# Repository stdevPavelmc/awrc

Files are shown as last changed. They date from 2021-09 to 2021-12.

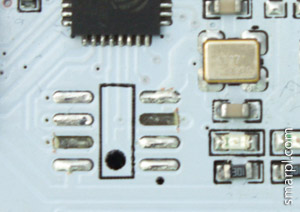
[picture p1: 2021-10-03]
doc/freeing up GPIO9 and GPIO10 smarpl.com_files/ESP8266-ESP-201-GPIO-mod-step3-IMG_7929.jpg

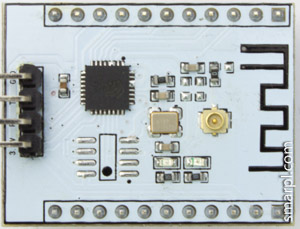
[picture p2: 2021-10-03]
doc/freeing up GPIO9 and GPIO10 smarpl.com_files/ESP8266-ESP-201-GPIO-mod-step1-IMG_7922.jpg

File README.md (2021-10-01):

# Amateur Wireless Rotor Controller

An arduino based rotor controller connected via WiFi using the ESP8266 MCU

## Rationale

Why use cables when you have wifi around?

The hamlib project has a simple TCP daemon for abstract the rotor control, so we implemented the basic commands for that protocol and simulate a `rotctld` instance right on the rotor hardware; as today most of the softwares I use supports rotctld directly.

A web interface with position and simple commands is built on, I will improve it with time but this is low priority.

## How to compile

We use platformio, not the Arduino IDE, and main development is on linux (It must work on Windows/Mac), so you need Vscode/Codium and the Platformio addon.

By now I'm managing the dependencies as git submodules, so to install them you must do on the console this:

```sh
git clone https://github.com/stdevPavelmc/awrc.git
cd awrc
git submodule update
```

I will port them to platformio.ini deps in the future. Now just open the Platformio IDE and open the project and run. If you have internet plarformio will install the frameworks and tools for you.

## Hardware

There is a folder named `awrc-kicad` that has the project for board and schematics.

## This is a work in progress

Until labeled otherwise this project is an `alpha` code.

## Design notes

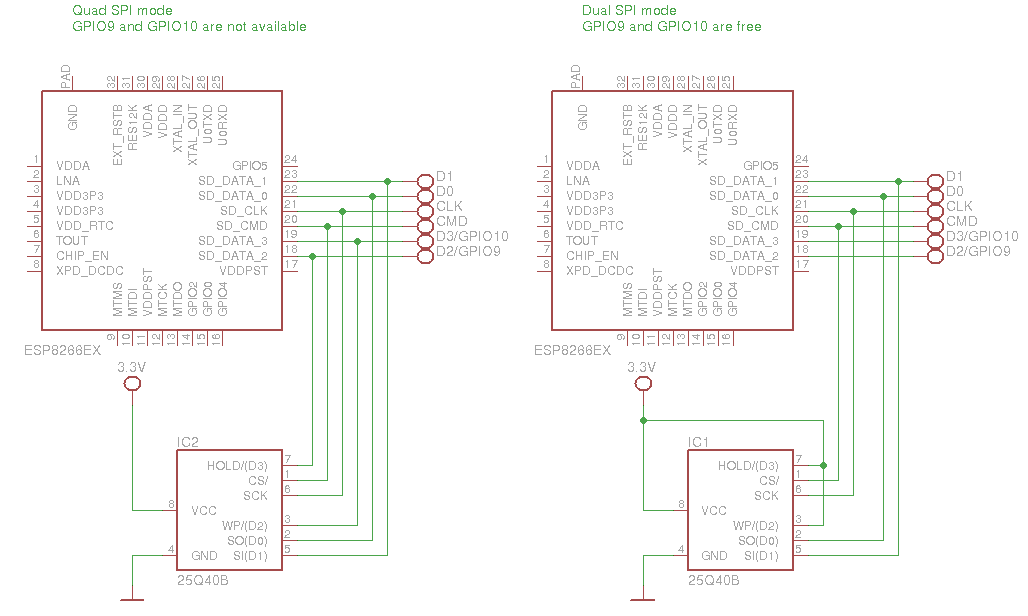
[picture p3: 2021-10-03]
doc/freeing up GPIO9 and GPIO10 smarpl.com_files/ESP8266-ESP-201-GPIO9-GPIO10-schematics.png

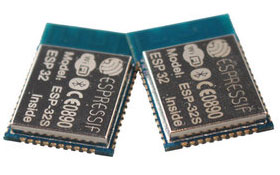
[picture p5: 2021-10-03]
doc/freeing up GPIO9 and GPIO10 smarpl.com_files/esp32s-x2-280.jpg

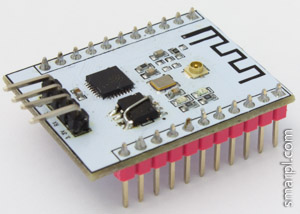
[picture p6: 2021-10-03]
doc/freeing up GPIO9 and GPIO10 smarpl.com_files/ESP8266-ESP-201-GPIO9-GPIO10-mod-IMG_7953.jpg

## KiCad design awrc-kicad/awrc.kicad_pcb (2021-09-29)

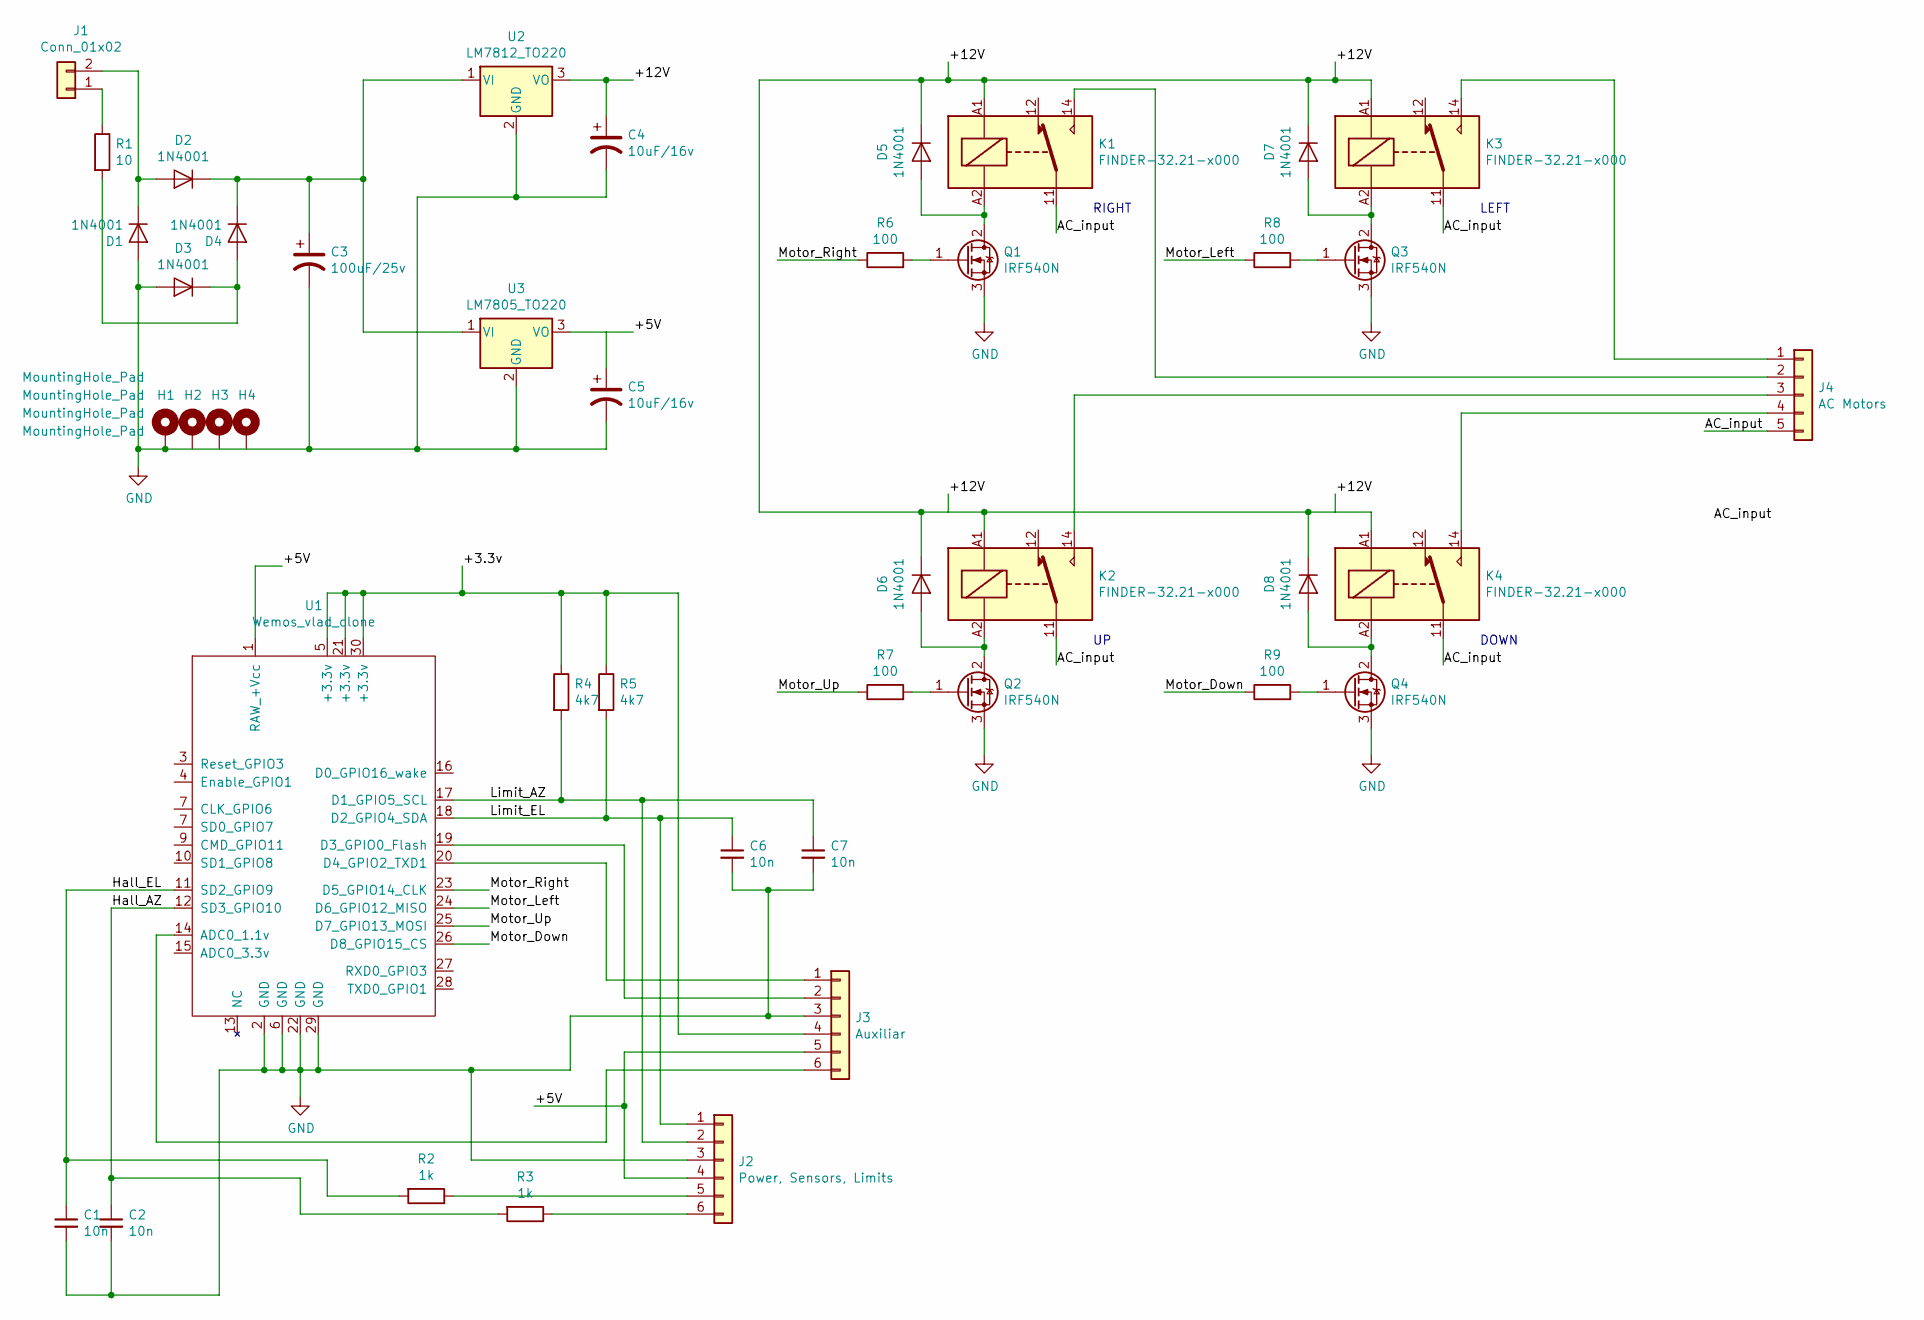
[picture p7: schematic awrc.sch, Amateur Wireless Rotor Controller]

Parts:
C1, C2, C6, C7: 10n; C_Disc_D7.5mm_W2.5mm_P5.00mm
C3: 100uF/25v; CP_Radial_D13.0mm_P5.00mm
C4, C5: 10uF/16v; CP_Radial_D10.0mm_P5.00mm
D1, D2, D3, D4, D5, D6, D7, D8: 1N4001; D_DO-41_SOD81_P10.16mm_Horizontal
H1, H2, H3, H4: MountingHole_Pad; MountingHole_3.2mm_M3_DIN965_Pad
J1: Conn_01x02; PinHeader_1x02_P2.54mm_Vertical
J2: Power, Sensors, Limits; PinHeader_1x06_P2.54mm_Vertical
J3: Auxiliar; PinHeader_1x06_P2.54mm_Vertical
J4: AC Motors; TerminalBlock_bornier-5_P5.08mm
K1, K2, K3, K4: FINDER-32.21-x000; Relay_THT_UPS_80H-1C-S
Q1, Q2, Q3, Q4: IRF540N; TO-220-3_Vertical
R1: 10; R_Axial_DIN0207_L6.3mm_D2.5mm_P10.16mm_Horizontal
R2, R3: 1k; R_Axial_DIN0207_L6.3mm_D2.5mm_P10.16mm_Horizontal
R4, R5: 4k7; R_Axial_DIN0207_L6.3mm_D2.5mm_P10.16mm_Horizontal
R6, R7, R8, R9: 100; R_Axial_DIN0207_L6.3mm_D2.5mm_P10.16mm_Horizontal
U1: Wemos_vlad_clone; Wemos_Clone
U2: LM7812_TO220; TO-220-3_Vertical
U3: LM7805_TO220; TO-220-3_Vertical

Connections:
/+3.3v: J3.4, R4.1, R5.1, U1.5 (+3.3v), U1.21 (+3.3v), U1.30 (+3.3v)
/+5V: C5.1, J2.4, J3.5, U1.1 (RAW_+Vcc), U3.3 (VO)
/+12V: C4.1, D5.1 (K), D6.1 (K), D7.1 (K), D8.1 (K), K1.A1, K2.A1, K3.A1, K4.A1, U2.3 (VO)
/AC_input: J4.5, K1.11, K2.11, K3.11, K4.11
/Hall_AZ: C2.1, R3.2, U1.12 (SD3_GPIO10)
/Hall_EL: C1.1, R2.2, U1.11 (SD2_GPIO9)
/Limit_AZ: C7.1, J2.2, R4.2, U1.17 (D1_GPIO5_SCL)
/Limit_EL: C6.1, J2.1, R5.2, U1.18 (D2_GPIO4_SDA)
/Motor_Down: R9.1, U1.26 (D8_GPIO15_CS)
/Motor_Left: R8.1, U1.24 (D6_GPIO12_MISO)
/Motor_Right: R6.1, U1.23 (D5_GPIO14_CLK)
/Motor_Up: R7.1, U1.25 (D7_GPIO13_MOSI)
GND: C1.2, C2.2, C3.2, C4.2, C5.2, C6.2, C7.2, D1.2 (A), D3.2 (A), H1.1, J2.3, J3.3, Q1.3 (S), Q2.3 (S), Q3.3 (S), Q4.3 (S), U1.2 (GND), U1.6 (GND), U1.22 (GND), U1.29 (GND), U2.2 (GND), U3.2 (GND)
unnamed: C3.1, D2.1 (K), D4.1 (K), U2.1 (VI), U3.1 (VI)
unnamed: D1.1 (K), D2.2 (A), J1.2
unnamed: D3.1 (K), D4.2 (A), R1.2
unnamed: D5.2 (A), K1.A2, Q1.2 (D)
unnamed: D6.2 (A), K2.A2, Q2.2 (D)
unnamed: D7.2 (A), K3.A2, Q3.2 (D)
unnamed: D8.2 (A), K4.A2, Q4.2 (D)
unnamed: J1.1, R1.1
unnamed: J2.5, R2.1
unnamed: J2.6, R3.1
unnamed: J3.1, U1.20 (D4_GPIO2_TXD1)
unnamed: J3.2, U1.19 (D3_GPIO0_Flash)
unnamed: J3.6, U1.14 (ADC0_1.1v)
unnamed: J4.1, K3.14
unnamed: J4.2, K1.14
unnamed: J4.3, K2.14
unnamed: J4.4, K4.14
unnamed: Q1.1 (G), R6.2
unnamed: Q2.1 (G), R7.2
unnamed: Q3.1 (G), R8.2
unnamed: Q4.1 (G), R9.2

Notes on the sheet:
RIGHT
LEFT
DOWN

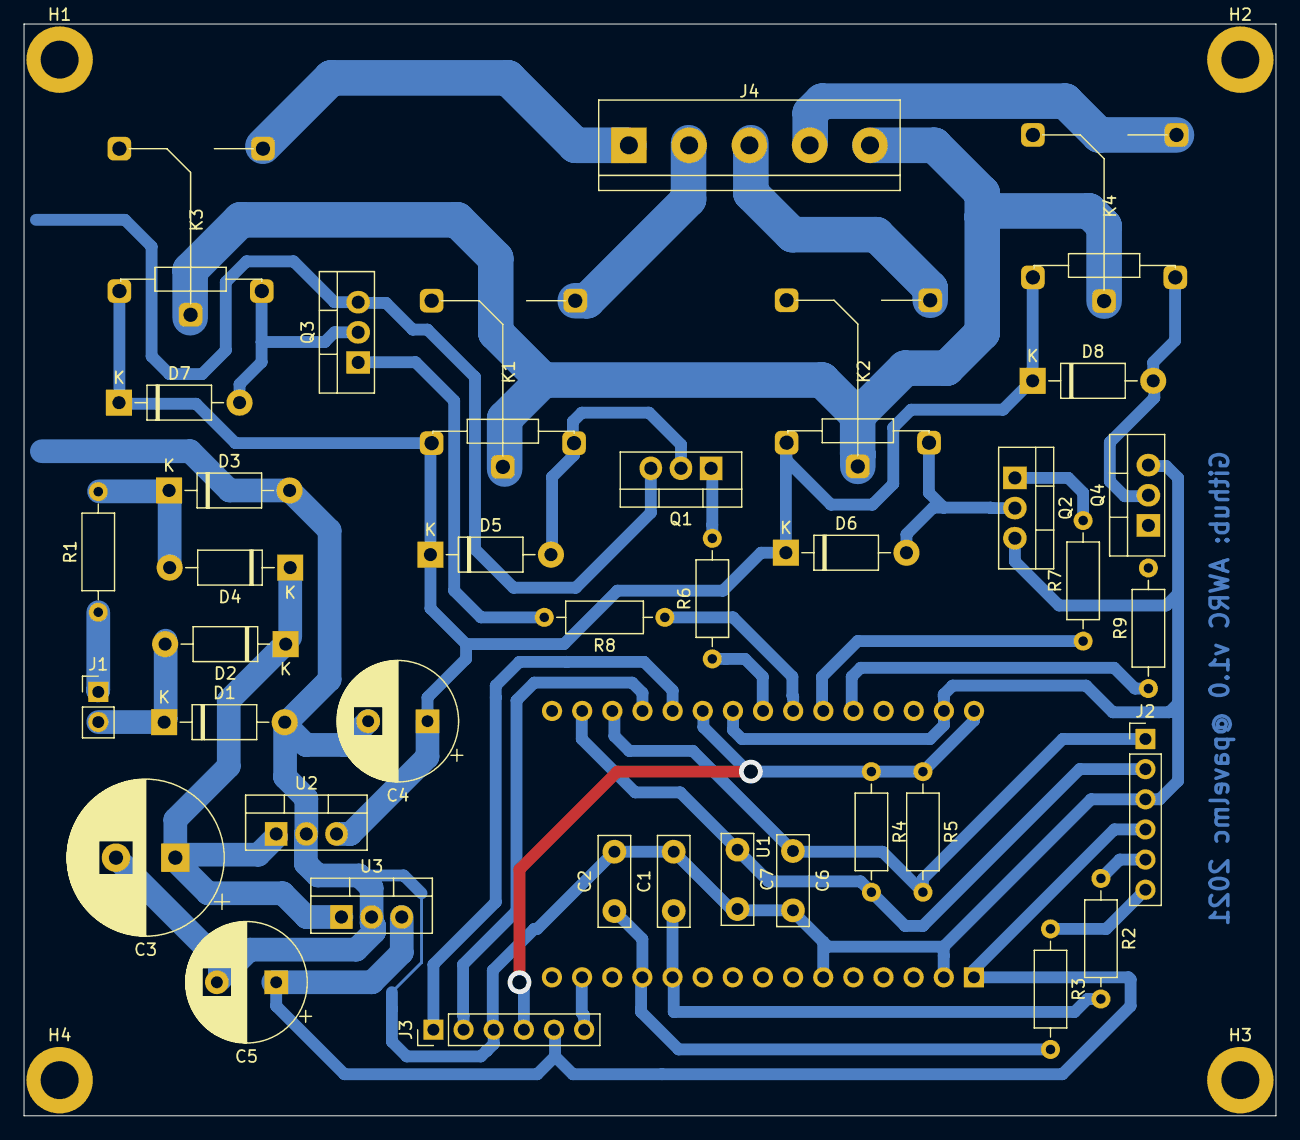
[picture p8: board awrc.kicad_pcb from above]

Board: 2 copper layers, 105.5 x 92.0 mm, 43 parts (0 on the bottom side), 34 nets.

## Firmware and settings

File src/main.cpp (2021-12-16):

// code exclusive for ESP8266
#if !(defined(ESP8266))
#error This code is intended to run on ESP8266 platform! Please check your Tools->Board setting.
#endif

// libraries
#include <ESP8266WiFi.h>
#include <ESP8266mDNS.h>
#include <ESPAsyncTCP.h>
#include <ESPAsyncWebServer.h>
#include <ESP8266WiFiMulti.h>
#include <ArduinoOTA.h>
#include <vector>
#include <arduino-timer.h>
#include "LittleFS.h"

// own / local
#include "eeprom.h"
#include "config.h"

// instantiating
Config conf;
States state = IDLE;
WebCmds wcmd = NONE;
ESP8266WiFiMulti wifiMulti;
//static DNSServer DNS;
AsyncWebServer webServer(80);
static std::vector<AsyncClient *> clients;
auto timer = timer_create_default(); // create a timer with default settings

/****************************************************/

// position variables

// actual values
float azimuth = 0.0;
float elevation = 0.0;
// target values
float tazimuth = 0.0;
float televation = 0.0;

// inertia on axes
float azinertia = 0;
float elinertia = 0;
// last time we moved on an axis
unsigned long aztime = 0;
unsigned long eltime = 0;
// stopped flags
bool azstopped = true;
bool elstopped = true;
// position to stop command
float azstoppos = 0;
float elstoppos = 0;

// pulse count vars
int azpulsecount = 0;
int elpulsecount = 0;
volatile sint8 azpulses = 0;
volatile sint8 elpulses = 0;

// direction (yes volatile as it will be use on a ISR routine)
volatile sint8 azdir = 0; //  1 = right / 0 = stoped / -1 = left
volatile sint8 eldir = 0; //  1 = up / 0 = stoped / -1 = down

// pulses/degrees ratio
float azdratio = DEF_AZDRATIO; // tentative value (see config.h)
float eldratio = DEF_ELDRATIO; // tentative value (see config.h)

// prototypes
void calc_position();

// SOME progmem

const char pstatus[] PROGMEM = "{\"az\": \"%az%\", \"el\": \"%el%\", \"taz\": \"%taz%\", \"tel\": \"%tel%\", \"status\": \"%st%\", \"rssi\": \"%rs%\"}";

/*****************************
 * Miscelaneous functions
******************************/

// split a string in parts by a given separator
String getValue(String data, char separator, int index)
{
    int found = 0;
    int strIndex[] = {0, -1};
    int maxIndex = data.length() - 1;

    for (int i = 0; i <= maxIndex && found <= index; i++)
    {
        if (data.charAt(i) == separator || i == maxIndex)
        {
            found++;
            strIndex[0] = strIndex[1] + 1;
            strIndex[1] = (i == maxIndex) ? i + 1 : i;
        }
    }

    return found > index ? data.substring(strIndex[0], strIndex[1]) : "";
}

/*********************************
 * Basic movements of the motors
**********************************/

// stop azimuth movement
void az_stop()
{
    bool mod = false;

    // full motor stop
    if (digitalRead(MRIGHT))
    {
        digitalWrite(MRIGHT, LOW);
        mod = true;
    }
    if (digitalRead(MLEFT))
    {
        digitalWrite(MLEFT, LOW);
        mod = true;
    }

    // reset only if neede
    if (mod)
    {
        // postition of the stop command
        azstoppos = azimuth;

        // induced pause
        delay(200);

        // dir update
        azdir = 0;

        // debug
#ifdef DEBUG
        Serial.println("AZ STOP");
#endif
    }
}

// stop elevation movement
void el_stop()
{
    bool mod = false;

    // full motor stop
    if (digitalRead(MUP))
    {
        digitalWrite(MUP, LOW);
        mod = true;
    }
    if (digitalRead(MDOWN))
    {
        digitalWrite(MDOWN, LOW);
        mod = true;
    }

    // reset only if neede
    if (mod)
    {
        // postition of the stop command
        elstoppos = elevation;

        // induced pause
        delay(200);

        // dir update
        eldir = 0;

        // debug
#ifdef DEBUG
        Serial.println("EL STOP");
#endif
    }
}

// move right
void move_right()
{
    // if already moving do nothing
    if (digitalRead(MRIGHT))
        return;

    // if was moving on the other direction stop & pause before move
    if (digitalRead(MLEFT))
        az_stop();

    // move
    digitalWrite(MRIGHT, HIGH);

    // dir update
    azdir = 1;

// debug
#ifdef DEBUG
    Serial.println("MOVE RIGHT");
#endif
}

// move left
void move_left()
{
    // if already moving do nothing
    if (digitalRead(MLEFT))
        return;

    // if was moving on the other direction stop & pause before move
    if (digitalRead(MRIGHT))
        az_stop();

    // move
    digitalWrite(MLEFT, HIGH);

    // dir update
    azdir = -1;

// debug
#ifdef DEBUG
    Serial.println("MOVE LEFT");
#endif
}

// move up
void move_up()
{
    // if already moving do nothing
    if (digitalRead(MUP))
        return;

    // if was moving on the other direction stop & pause before move
    if (digitalRead(MDOWN))
        el_stop();

    // move
    digitalWrite(MUP, HIGH);

    // dir update
    eldir = 1;

// debug
#ifdef DEBUG
    Serial.println("MOVE UP");
#endif
}

// move down
void move_down()
{
    // if already moving do nothing
    if (digitalRead(MDOWN))
        return;

    // if was moving on the other direction stop & pause before move
    if (digitalRead(MUP))
        el_stop();

    // move
    digitalWrite(MDOWN, HIGH);

    // dir update
    eldir = -1;

    // debug
#ifdef DEBUG
    Serial.println("MOVE DOWN");
#endif
}

/************************************************
 *  Command interface functions
*************************************************/

// set position
void set_position(String data)
{
    // replace "," by "."
    data.replace(",", ".");

    // extract numbers
    float a = getValue(data, 32, 1).toFloat();
    float e = getValue(data, 32, 2).toFloat();

    // numbers limits
    if (a > MAXAZIMUTH)
        a = MAXAZIMUTH;
    if (a < MINAZIMUTH)
        a = MINAZIMUTH;
    if (e > MAXELEVATION)
        e = MAXELEVATION;
    if (e < MINELEVATION)
        e = MINELEVATION;

    // finaly set them on the env as target
    tazimuth = a;
    televation = e;

    // declare status
    state = TRACKING;

    // debug
#ifdef DEBUG
    Serial.print("P ");
    Serial.print(tazimuth);
    Serial.print(" ");
    Serial.println(televation);
#endif
}

// get position
String get_position()
{
    Serial.print("azp/az: ");
    Serial.print(azpulsecount);
    Serial.print("/");
    Serial.print(azimuth);
    Serial.print(" elp/el: ");
    Serial.print(elpulsecount);
    Serial.print("/");
    Serial.println(elevation);

    // build the response string
    char az[8];
    char el[8];
    dtostrf(azimuth, 3, 2, az);
    dtostrf(elevation, 3, 2, el);
    String result = String(az) + String("\n") + String(el) + String("\n");
    result.replace(".", ",");
    return result;
}

// get calibration parameters
String get_calibration()
{
    Serial.print("AZ ratio: ");
    Serial.print(azdratio);
    Serial.print(" | EL ratio: ");
    Serial.println(eldratio);

    // build the response string
    char azd[8];
    char eld[8];
    dtostrf(azdratio, 3, 2, azd);
    dtostrf(eldratio, 3, 2, eld);
    String result = String("AZd: ") + String(azd) + String("\n") + String("ELd: ") + String(eld) + String("\n");
    result.replace(".", ",");
    return result;
}

// full stop
void full_stop()
{
    // motors
    // az
    digitalWrite(MRIGHT, LOW);
    digitalWrite(MLEFT, LOW);
    // el
    digitalWrite(MUP, LOW);
    digitalWrite(MDOWN, LOW);

    // dirs
    azdir = 0;
    eldir = 0;

    // target = actual
    tazimuth = azimuth;
    televation = elevation;

    // state
    state = IDLE;

    // debug
#ifdef DEBUG
    Serial.println("FULL STOP");
#endif
}

// parking
void parking()
{
    // move to az = 0 / el = 0 with no error, 0,000 flat!
    tazimuth = 0;
    televation = 0;

    // going to left/down all the way down
    move_left();
    move_down();
    delay(100);
    if (digitalRead(ELLIMIT) or digitalRead(AZLIMIT))
        return;

    // if you reached here then both limits hare hit

    // reset pulsescount
    azpulsecount = 0;
    elpulsecount = 0;
    // reset  position
    azimuth = 0;
    elevation = 0;

    // set state
    state = IDLE;
}

// make a calibration cycle
void calibration()
{
    state = CALIBRATING;

    // going to left/down all the way down
    move_left(); move_down();
    while (digitalRead(ELLIMIT) or digitalRead(AZLIMIT))
    {
        delay(200);
        Serial.print(".");
        calc_position();
    }

    // stop all movement
    full_stop();

    // set state again
    state = CALIBRATING;

    // end the printing
    Serial.println(".");
    Serial.println("Done parking");
    Serial.println("Blocking calibration azimuth...");

    // reset pulses
    azpulsecount = 0;
    elpulsecount = 0;

    // going to left/down all the way down
    move_right();
    move_up();
    while (digitalRead(ELLIMIT) or digitalRead(AZLIMIT))
    {
        delay(200);
        Serial.print(".");
    }

    // end the printing
    Serial.println(".");
    Serial.println("Done");

    // calculation of the ration
    if (azpulsecount > 0)
        azdratio = azpulsecount / (MAXAZIMUTH - MINAZIMUTH);
    else
        azdratio = 1;
    
    if (elpulsecount > 0)
        eldratio = elpulsecount / (MAXELEVATION - MINELEVATION);
    else
        eldratio = 1;
    
    // debug
    Serial.print("AZratio: ");
    Serial.print(azdratio);
    Serial.print("ELratio: ");
    Serial.println(eldratio);

    // save conf
    saveConf(conf);

    // state
    state = IDLE;
}

// '\dump_state' command
String dump_state()
{
    String endc = "\n";
    String result = String("0") + endc;
    result += String("1") + endc;
    result += String(MINAZIMUTH) + endc;
    result += String(MAXAZIMUTH) + endc;
    result += String(MINELEVATION) + endc;
    result += String(MAXELEVATION) + endc;

    return result;
}

// handle the client messages
String msg_handle(char *data)
{
    String d = String(data);
    String result = String("RPRT 0\n");
    char command = d.charAt(0);

    // if calibrating just reply ok and return
    if (state == CALIBRATING)
        return String(result);

    // select the action depending on the command
    switch (command)
    {
    // set position
    case 80: // P
        set_position(d);
        break;
    // request position
    case 112: // p
        result = get_position();
        break;
    // stop
    case 83: // S
        full_stop();
        break;
    // parking
    case 75: // K
        state = PARKING;
        break;
    // make a calibration cycle
    case 43: // C
        state = CALIBRATING;
        calibration();
        break;
    // retrieve calibration parameters
    case 99: // c
        result = get_calibration();
        break;
    // move RIGHT
    case 114: // r
    case  82: // R
        move_right();
        state = MANUAL;
        break;
    // move LEFT
    case 108: // l
    case  76:  // L
        move_left();
        state = MANUAL;
        break;
    // move UP
    case 117: // u
    case  85:  // U
        move_up();
        state = MANUAL;
        break;
    // move DOWN
    case 100: // d
    case 68:  // D
        move_down();
        state = MANUAL;
        break;

    case 92: // \dump_state
        // call the dump procedure
        result = dump_state();
        break;

    default:
        break;
    }

// debug
#ifdef DEBUG
    Serial.println(result);
#endif

    // client answer
    return result;
}

/*******************
 * TCP socket part
 *******************/

static void handleError(void *arg, AsyncClient *client, int8_t error)
{
    Serial.printf("\n connection error %s from client %s \n", client->errorToString(error), client->remoteIP().toString().c_str());
}

static void handleData(void *arg, AsyncClient *client, void *data, size_t len)
{
    // prepare buffers
    char buff[18];
    memset(buff, '\0', 18);
    char reply[32];
    memset(reply, '\0', 32);

    // copy only the starting 18 chars of the payload
    memcpy(buff, data, len);

    // send the data to the handle function
    String answer = msg_handle(buff);

    // reply to client
    if (client->space() > 32 && client->canSend())
    {
        memcpy(reply, answer.c_str(), strlen(answer.c_str()));
        client->add(reply, strlen(reply));
        client->send();
    }
}

static void handleDisconnect(void *arg, AsyncClient *client)
{
    Serial.printf("\n client %s disconnected \n", client->remoteIP().toString().c_str());
}

static void handleTimeOut(void *arg, AsyncClient *client, uint32_t time)
{
    Serial.printf("\n client ACK timeout ip: %s \n", client->remoteIP().toString().c_str());
}

static void handleNewClient(void *arg, AsyncClient *client)
{
    Serial.printf("\n new client has been connected to server, ip: %s\n", client->remoteIP().toString().c_str());

    // add to list
    clients.push_back(client);

    // register events
    client->onData(&handleData, NULL);
    client->onError(&handleError, NULL);
    client->onDisconnect(&handleDisconnect, NULL);
    client->onTimeout(&handleTimeOut, NULL);
}

/************************************
 * Position calculations and checks
*************************************/

// calc position
void calc_position()
{
    if (azpulsecount != 0)
    {
        azimuth = float(azpulsecount) / azdratio;
    }
    else
    {
        azimuth = 0;
    }

    if (elpulsecount != 0)
        elevation = float(elpulsecount) / eldratio;
    else
        elevation = 0;

    // failsafe AZ
    if (azimuth > MAXAZIMUTH) {azimuth = MAXAZIMUTH;}
    if (azimuth < MINAZIMUTH) {azimuth = MINAZIMUTH;}
    // failsafe EL
    if (elevation > MAXELEVATION) {elevation = MAXELEVATION;}
    if (elevation < MINELEVATION) {elevation = MINELEVATION;}
}

// update the real positions from pulses
void update_position()
{
    // disable interrupt
    noInterrupts();

    // sum azimuth
    if (azpulses != 0)
    {
        azpulsecount += azpulses;
        azpulses = 0;

        // reset last movement time mark
        aztime = millis();
    }

    // sum elevation
    if (elpulses != 0)
    {
        elpulsecount += elpulses;
        elpulses = 0;

        // reset last movement time mark
        eltime = millis();
    }

    // enable interrupts
    interrupts();

    // update az/el
    calc_position();
}

// we need to move on az?
void need2move_az(float delta)
{
    // manual
    if (state == MANUAL)
        return;

    // absolute value of delta
    float adelta = abs(delta);

    // inertia and i'm moving to make the stop
    if (azinertia != 0 and azdir != 0)
    {
        // moving right and hit inertia window
        if ((azdir == 1) and (delta - azinertia) <= 0)
        {
            az_stop();
            return;
        }

        // moving left and hit inertia window
        if ((azdir == -1) and (delta + azinertia) >= 0)
        {
            az_stop();
            return;
        }
    }

    // from moving left
    if (azdir == -1 and delta >= 0)
    {
        az_stop();
        return;
    }

    // from moving right
    if (azdir == 1 and delta <= 0)
    {
        az_stop();
        return;
    }

    // from stopped position
    if (azdir == 0)
    {
        // mode right
        if (delta > 0 and adelta > MINERROR)
        {
            move_right();
            return;
        }

        // mode left
        if (delta < 0 and adelta > MINERROR)
        {
            move_left();
            return;
        }
    }
}

// we need to move on el?
void need2move_el(float delta)
{
    // manual
    if (state == MANUAL)
        return;

    // absolute value of delta
    float adelta = abs(delta);

    // inertia and i'm moving to make the stop
    if (elinertia != 0 and eldir != 0)
    {
        // moving up and hit inertia window
        if ((eldir == 1) and (delta - elinertia) <= 0)
        {
            el_stop();
            return;
        }

        // moving down and hit inertia window
        if ((eldir == -1) and (delta + elinertia) >= 0)
        {
            el_stop();
            return;
        }
    }

    // from moving down
    if (eldir == -1 and delta >= 0)
    {
        el_stop();
        return;
    }

    // from moving up
    if (eldir == 1 and delta <= 0)
    {
        el_stop();
        return;
    }

    // from stopped position
    if (eldir == 0)
    {
        // move up
        if (delta > 0 and adelta > MINERROR)
        {
            move_up();
            return;
        }

        // move down
        if (delta < 0 and adelta > MINERROR)
        {
            move_down();
            return;
        }
    }
}

// check if we need to move and activate the corresponding motors
void need2move()
{
    // azimuth difference
    float daz = tazimuth - azimuth;
    // move if needed
    need2move_az(daz);

    // elevation difference
    float del = televation - elevation;
    // move if needed
    need2move_el(del);
}

// Limits
void limits()
{
    // azimuth
    if (!digitalRead(AZLIMIT))
    {
        // moving right
        if (azdir > 0)
        {
            azpulsecount = MAXAZIMUTH * azdratio;
            digitalWrite(MRIGHT, LOW);   
        }
        // moving left
        if (azdir < 0)
        {
            azpulsecount = 0;
            digitalWrite(MLEFT, LOW);
        }
        // stoppped
        azdir = 0;
    }

    // elevation
    if (!digitalRead(ELLIMIT))
    {
        // moving UP
        if (eldir > 0)
        {
            elpulsecount = MAXELEVATION * eldratio;
            digitalWrite(MUP, LOW);
        }
        // moving down
        if (eldir < 0)
        {
            elpulsecount = 0;
            digitalWrite(MDOWN, LOW);
        }
        // stoppped
        eldir = 0;
    }
}

// know if moving and calc the inertia of the axis
void ismoving()
{
    // az
    unsigned long delta = millis() - aztime;
    if (delta > AZSTOPT)
    {
        azstopped = true;

        // calc inertia only if tracking
        if (state == TRACKING)
        {
            if (azinertia == 0)
                azinertia = abs(azimuth - azstoppos);
            else
                azinertia = (azinertia + abs(azimuth - azstoppos)) / 2;

        }
    }
    else
        azstopped = false;

    // el
    delta = millis() - eltime;
    if (delta > ELSTOPT)
    {
        elstopped = true;

        // calc inertia only if tracking
        if (state == TRACKING)
        {
            if (elinertia == 0)
                elinertia = abs(elevation - elstoppos);
            else
                elinertia = (elinertia + abs(elevation - elstoppos)) / 2;
        }
    }
    else
        elstopped = false;
}

/**********************
 * Setup funtions
***********************/

// pin mode declaration
void pin_setup()
{
    // movement outputs
    pinMode(MRIGHT, OUTPUT);
    pinMode(MLEFT, OUTPUT);
    pinMode(MDOWN, OUTPUT);
    pinMode(MUP, OUTPUT);
    digitalWrite(MRIGHT, LOW);
    digitalWrite(MLEFT, LOW);
    digitalWrite(MUP, LOW);
    digitalWrite(MDOWN, LOW);

    // Input movement interrupts
    pinMode(IIAZ, INPUT);
    pinMode(IIEL, INPUT);

    // movement current sensor
    pinMode(AZLIMIT, INPUT);
    pinMode(ELLIMIT, INPUT);
}

// wifi config
void wifi_config()
{
    // set hostname
    WiFi.hostname(HOSTNAME);

    // start wifi handling
    WiFi.mode(WIFI_STA);
    wifiMulti.addAP("termopilas", "QF9vhtwj");
    wifiMulti.addAP("CO7WT", "Xilantr0!!!");

    Serial.println("Connecting to Wifi...");
    if (wifiMulti.run() == WL_CONNECTED)
    {
        Serial.println("");
        Serial.println("WiFi connected");
        Serial.println("IP address: ");
        Serial.println(WiFi.localIP());
    }
    else
    {
        Serial.println("No connection detected...");
    }

    // register mDNS and names
    if (!MDNS.begin(HOSTNAME))
    {
        Serial.println("Error setting up MDNS responder!");
    }
    else
    {
        MDNS.addService("rotctld", "tcp", TCP_PORT);
        MDNS.addService("http", "tcp", 80);
        Serial.print("mDSN name registered ");
        Serial.print(HOSTNAME);
        Serial.println(".local");
    }
}

// tcp socket to sumulate a rotctld
void rotctld_setup()
{
    AsyncServer *tcpserver = new AsyncServer(TCP_PORT); // start listening on tcp port 7050
    tcpserver->onClient(&handleNewClient, tcpserver);
    tcpserver->begin();
}
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
void loop()
{
    // multiwifi run
    wifiMulti.run();

    // ota handler
    ArduinoOTA.handle();

    // catch web commands
    webCommands();

    // check limits
    limits();

    // timer tick
    timer.tick();

    // know the real status (moving/stopped)
    ismoving();

    // check if the position changed
    update_position();

    // calibrating
    if (state != CALIBRATING)
    {
        // parking
        if (state == PARKING)
        {
            parking();
        }
        else
        {
            // need to move, always AFTER the update_position one
            need2move();
        }
    }

    // mDNS update
    MDNS.update();

    // delay to make the wifi handling
    delay(1);
}

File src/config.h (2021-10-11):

#ifndef CONFIG_H
#define CONFIG_H

/******** DEBUG FLAG **********/
#define DEBUG 1

/************ TCP/IP settings ****************/

#define HOSTNAME "awrc"
#define TCP_PORT 4533   // default for rotctld

/************ PIN definitions ****************/
// Outputs movement
#define MRIGHT  14 // D5
#define MLEFT   12 // D6
#define MUP     13 // D7
#define MDOWN   15 // D8

// Input movement interrupts (change)
#define IIAZ 10 // SD3
#define IIEL  9 // SD2

// movement current sensor
#define AZLIMIT 5 // D1
#define ELLIMIT 4 // D2

/************* Coordinate limits *************/

// Polar coordinates limits
const float MAXAZIMUTH = 360.0;
const byte MINAZIMUTH = 0;
const float MAXELEVATION = 72.0;
const byte MINELEVATION = 0.0;

// default values for config (only re az/el delta ratio)
#define DEF_AZDRATIO 8.777777778  // 3160 pulses/360 degrees
#define DEF_ELDRATIO 17.575342466 // 1283 pulses/72 degrees

// minimum error to track
const float MINERROR = 5.0;

// time limits to know we are stopped (millis)
#define AZSTOPT 1000
#define ELSTOPT 1000

/***************** EEPROM **********************/

// EEPROM size
#define EES 22

// config Struct
typedef struct
{
    float azdratio;
    float eldratio;
    int azpulses;
    int elpulses;
    uint32_t crc32;
} Config;

// autosave interval (in seconds)
#define AUTOSAVE_INTERVAL 30

// State of the system
enum States
{
    IDLE,
    TRACKING,
    MANUAL,
    CALIBRATING,
    PARKING,
    OTA
};

// Web commands
enum WebCmds
{
    NONE,
    CAL,
    STOP,
    PARK,
    RIGHT,
    LEFT,
    UP,
    DOWN
};

#endif // CONFIG_H

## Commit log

2021-09-22 Add pinout and pin definitions
2021-09-23 huge update, a lot of functions but hitting a 'ISR not in iRAM' error and reboot, need to investigate that
    [config.h, main.cpp]
2021-09-23 Classic OTA, Debug, fix the TCP socket handling, etc...
    [main.cpp]
2021-09-23 Add parking option and fix the removal of EleganOTA that broke the webserver
    [main.cpp]
2021-09-23 fix full stop while parking and some others details
    [main.cpp]
2021-09-23 First part of the calibration cycle, need to work on the eeprom saving and retrieving
2021-09-23 add crc and timer support for the eeprom feature
2021-09-27 Add Kicad files for the hardware
    This are the kicad files on revision 1.0
    [awrc.kicad_pcb, awrc.sch]
2021-10-01 Optimize JS, actions on buttons, etc.
2021-10-01 Useing enums to get track os state and using enum flags to trigger web commands
2021-10-03 Modified esp8266 to release GPIO9/10 for hall pulses, details on docs
2021-10-08 Add a 'c' command to show calibration results and change calibration command from 'c' to 'C' to match hamlib standard
2021-10-08 Add el ismoving code and improve precedence on need2move_az
2021-10-09 Port the inertia algorithm to elevation and fix the OTA update
    [main.cpp]
2021-10-11 Add html/css glue to make buttons functions up/down/right/left/stop
2021-10-14 Web interface adapt to mobile devices
2021-12-16 Add the doc of the dump_state command
    [dump_state.sample.txt]
